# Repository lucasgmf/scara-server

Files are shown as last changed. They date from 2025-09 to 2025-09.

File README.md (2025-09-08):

# 4-DOF Educational SCARA Manipulator
An affordable, open-source robotic manipulator designed for educational environments, featuring four degrees of freedom and an integrated gripper system. Master's thesis in Electrical and Computer Engineering at the [Faculty of Engineering, University of Porto](https://www.up.pt/feup/en/).

## Dependencies
This project requires the following dependencies:

- [Python](https://www.python.org/)
- [ESP-IDF (Espressif IoT Development Framework)](https://docs.espressif.com/projects/esp-idf/en/stable/esp32/get-started/index.html)

If you are using the provided [Nix flake](./flake.nix), most of the dependencies are already handled.  
Make sure to install the ESP-IDF toolchain and source it before building:

```bash
. ~/esp-idf/export.sh
```

## Build & Flash (Makefile)
This project includes a `Makefile` that simplifies the workflow with the ESP-IDF toolchain.  
Instead of remembering multiple commands, you can just run `make` and it will take care of everything.

### Targets
- **`build`**  
  - Converts the web page `components/network/page.html` into a C header file (`page_html.h`) using `xxd`.  
    This allows embedding HTML directly into the firmware.  
  - Runs `idf.py build` to compile the project with ESP-IDF.

- **`flash`**  
  - Uploads the compiled firmware to the ESP32 via the specified serial port:  
    ```bash
    idf.py -p /dev/ttyUSB0 flash
    ```
  - If your board shows up differently, you can change the port (e.g. `/dev/ttyACM0`).

- **`monitor`**  
  - Starts the ESP-IDF serial monitor:  
    ```bash
    idf.py monitor
    ```
  - Useful for reading logs and debugging output from the ESP32.

- **`all`**  
  - Runs `build → flash → monitor` in sequence.  
  - This is also the **default target**, meaning just running:
    ```bash
    make
    ```
    will compile, flash, and open the serial monitor in one step.

### Example workflow
```bash
# Build the firmware only
make build

# Flash the firmware to ESP32
make flash

# Open the ESP-IDF monitor
make monitor

# Do everything: build, flash, and monitor
make
```

## Internet Connectivity
To enable Wi-Fi connectivity on the ESP32, you need to provide your own network credentials.

1. Open the template file located at:
```bash
components/network/credentials_TEMPLATE.h
```

2. Edit the file and replace the placeholders with your Wi-Fi details:
```c
   #ifndef CREDENTIALS_H
   #define CREDENTIALS_H

   #define WIFI_USERNAME "upxxxxxxxxx@up.pt"
   #define WIFI_PASSWORD "password"

   #endif
```
Where:
   - WIFI_USERNAME → your Wi-Fi SSID (e.g., the network name or enterprise username)
   - WIFI_PASSWORD → your Wi-Fi password

3. Save the file and rename it from:
   credentials_TEMPLATE.h
   to:
   credentials.h

Do not commit your personal credentials to GitHub ;).

# Kinematics Study
This repository also contains a directory for studying the kinematics of the SCARA robot.

You can find it here:
```bash
kinematics-study/kinematics.ipynb
```
Open the Jupyter notebook to explore the mathematical models and simulations of the robot's kinematics.

Tip: To run the notebook, make sure you have Python and Jupyter installed. Or run the notebook directly in [Google Colab](https://colab.google/).

# SCARA Robot Schematic
The electrical schematic of the SCARA robot is included in this repository.

Files included:
1. `schematic/scara_robot.json`  
   - This is the EasyEDA project file.  
   - You can open it directly in [EasyEDA](https://easyeda.com) to view, edit, or export the schematic.

2. `schematic/scara_robot.pdf`  
   - A static PDF version of the schematic for easy reference or printing.

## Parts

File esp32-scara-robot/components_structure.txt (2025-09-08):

components/
├── app/
│   ├── scara_controller.c 
│   └── scara_tasks.c
│
├── control/
│   └── pid.c 
│
├── devices/
│   ├── mag_encoder.c
│   ├── loadcell.c
│   └── motor_d.c
│
├── drivers/
│   └── i2c_bus.c          
│
├── hal/
│   ├── encoder.c   
│   ├── switch_h.c
│   ├── i2c_multiplexer.c
│   └── motor.c
│
└── network/
    ├── wifi_manager
    └── page.html

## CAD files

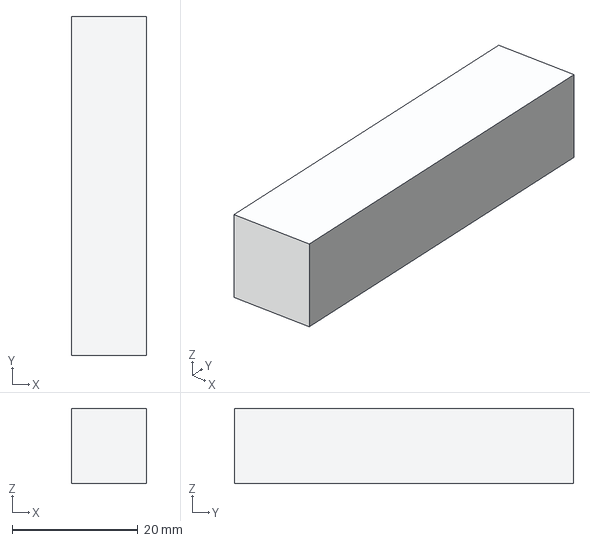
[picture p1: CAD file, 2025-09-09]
cad/step-files/Devices/Loadcell1.step
12.0 x 54.0 x 12.0 mm

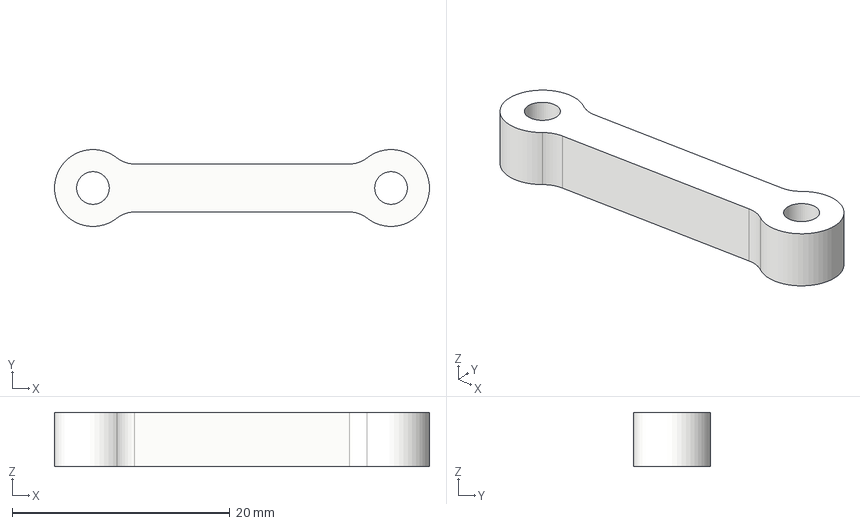
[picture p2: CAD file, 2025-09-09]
cad/step-files/FingerHolder.step
34.4 x 7.05 x 5.00 mm

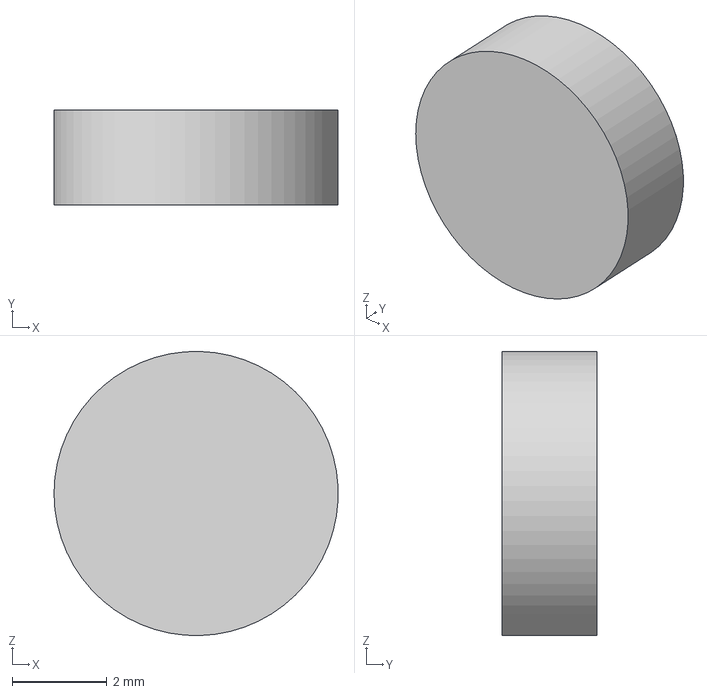
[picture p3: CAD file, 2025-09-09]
cad/step-files/Devices/magnet.step
6.00 x 2.00 x 6.00 mm

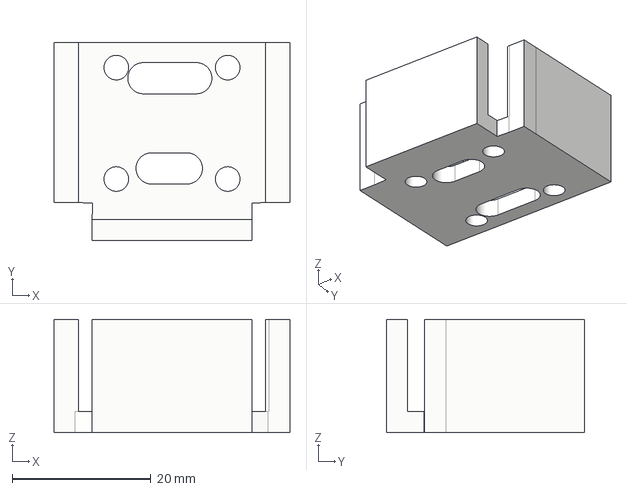
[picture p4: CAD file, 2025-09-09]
cad/step-files/EncoderHolderType1.step
34.0 x 28.5 x 16.3 mm

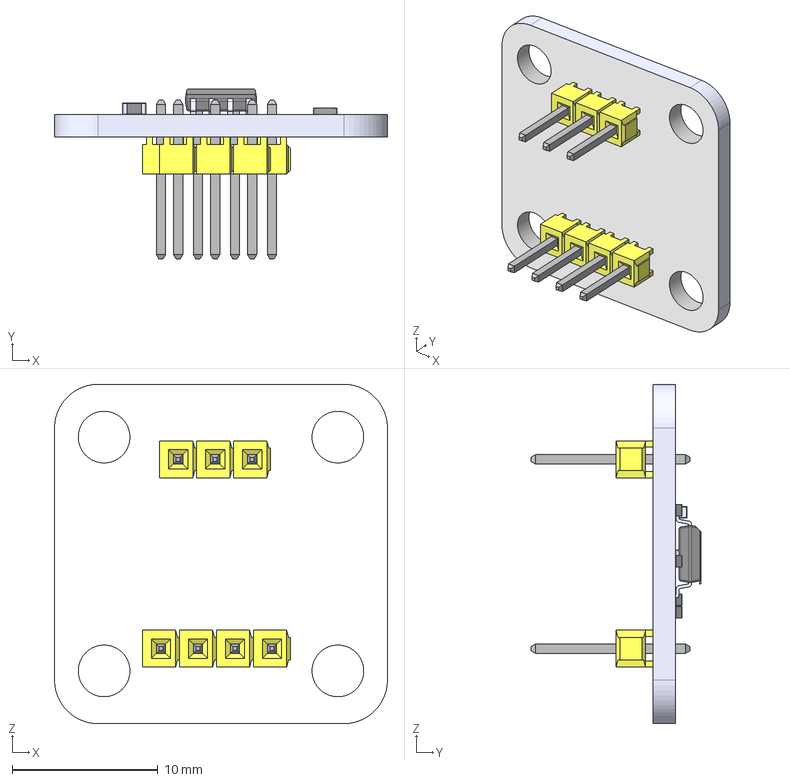
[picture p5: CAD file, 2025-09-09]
cad/step-files/Devices/AS5600.step
22.9 x 11.7 x 23.3 mm

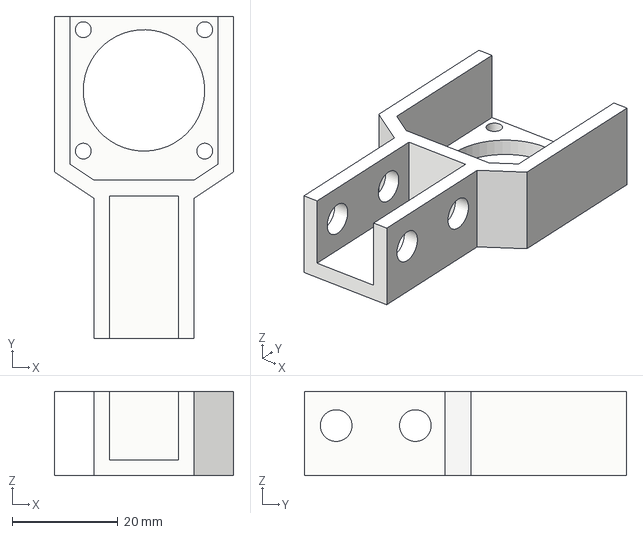
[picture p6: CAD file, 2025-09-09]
cad/step-files/LinkExtender.step
34.0 x 61.0 x 16.0 mm

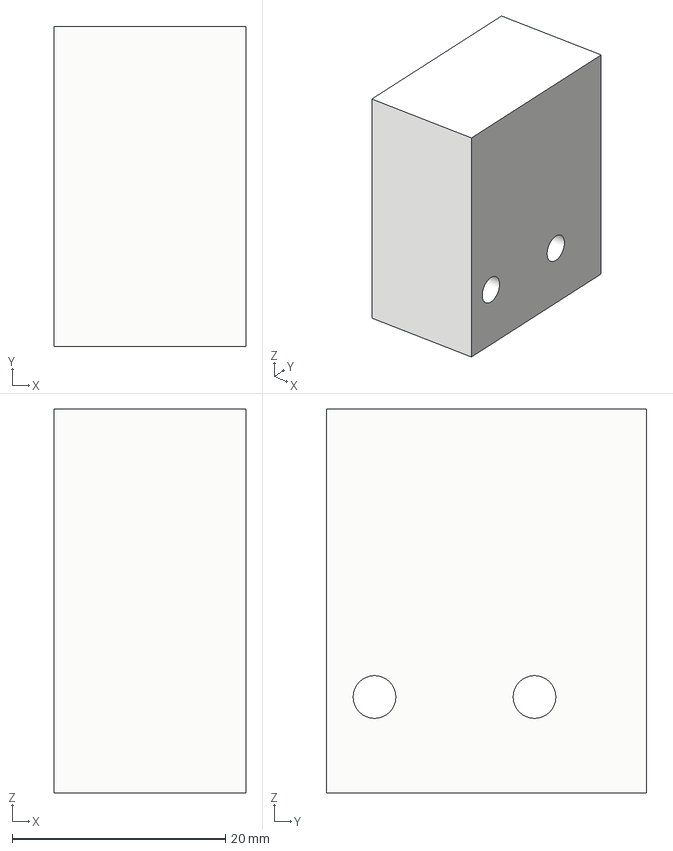
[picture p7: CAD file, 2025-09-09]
cad/step-files/Devices/LoadcellBase.step
18.0 x 30.0 x 36.0 mm

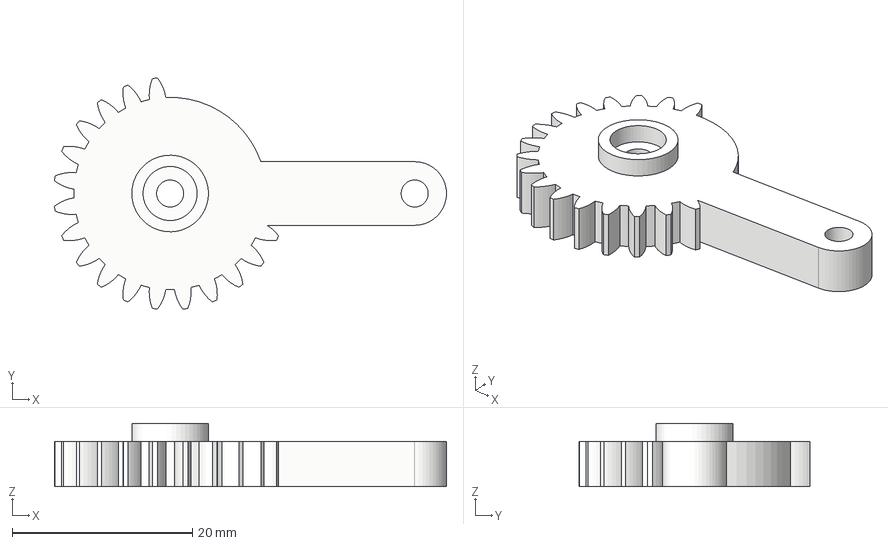
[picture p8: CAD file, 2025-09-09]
cad/step-files/GearArmType1.step
43.5 x 25.6 x 7.00 mm

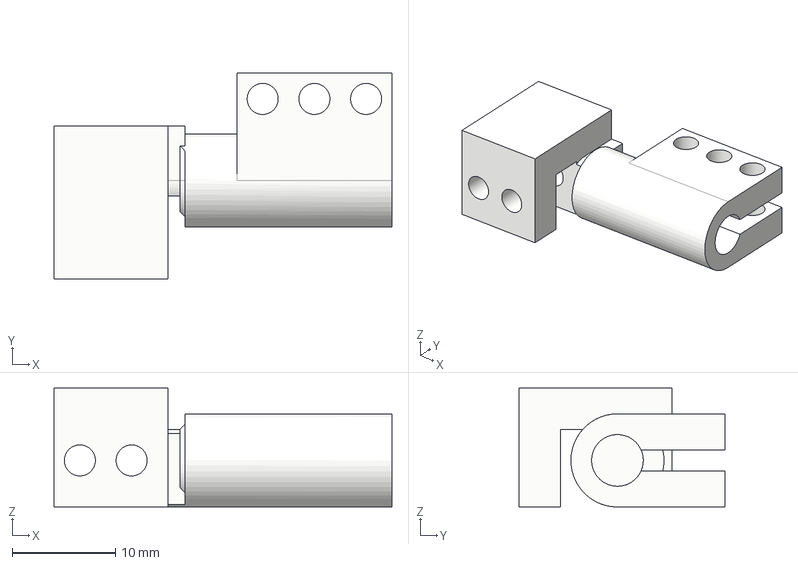
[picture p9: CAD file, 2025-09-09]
cad/step-files/NemaLinkGripper.step
32.7 x 19.9 x 11.5 mm

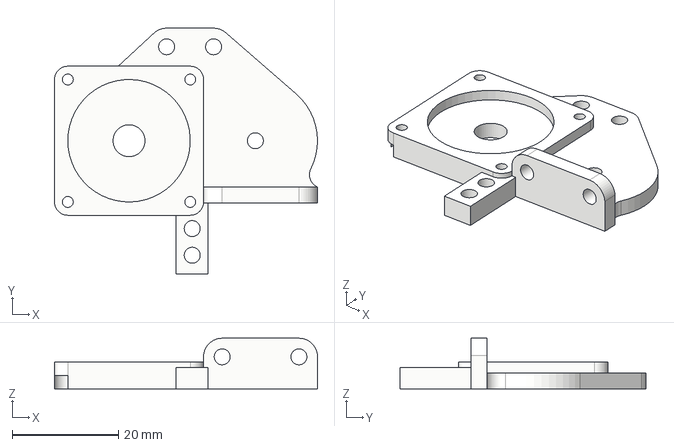
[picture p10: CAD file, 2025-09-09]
cad/step-files/ClawBody.step
49.4 x 46.1 x 9.50 mm

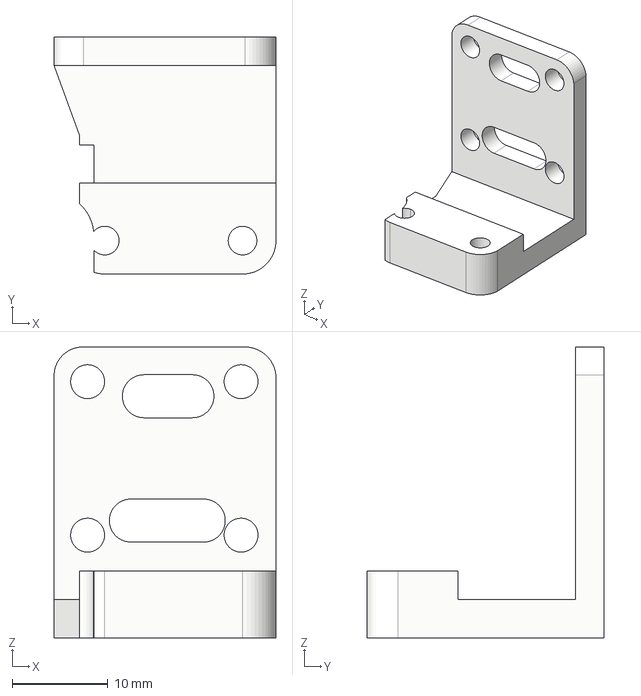
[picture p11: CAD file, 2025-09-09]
cad/step-files/EncoderHolderType2.step
23.2 x 24.8 x 30.4 mm

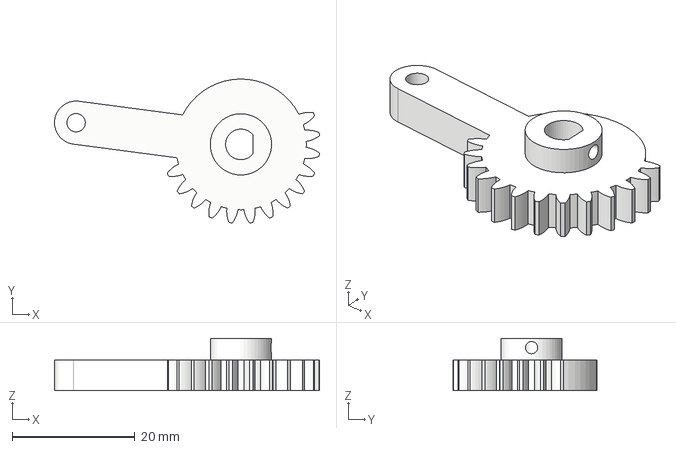
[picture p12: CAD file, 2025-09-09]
cad/step-files/GearArmType2.step
43.2 x 23.5 x 8.50 mm

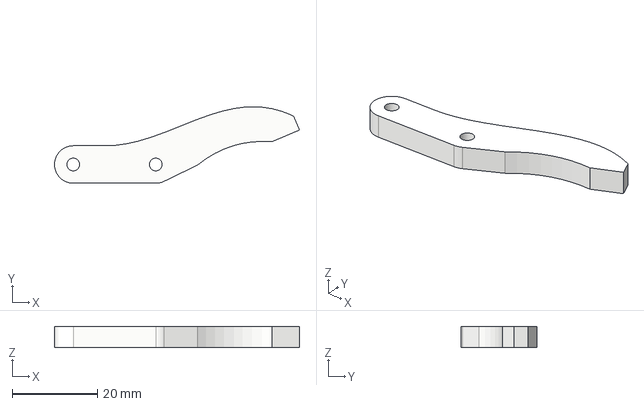
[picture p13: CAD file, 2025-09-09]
cad/step-files/Finger.step
57.6 x 18.0 x 5.00 mm

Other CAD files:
cad/fusion-files(.f3d)/ClawBody.f3d
cad/fusion-files(.f3d)/Devices/AS5600.f3d
cad/fusion-files(.f3d)/Devices/Loadcell1.f3d
cad/fusion-files(.f3d)/Devices/LoadcellBase.f3d
cad/fusion-files(.f3d)/Devices/NEMA11.f3d
cad/fusion-files(.f3d)/Devices/magnet.f3d
cad/fusion-files(.f3d)/EncoderHolderType1.f3d
cad/fusion-files(.f3d)/EncoderHolderType2.f3d
cad/fusion-files(.f3d)/Finger.f3d
cad/fusion-files(.f3d)/FingerHolder.f3d
cad/fusion-files(.f3d)/GearArmType1.f3d
cad/fusion-files(.f3d)/GearArmType2.f3d
cad/fusion-files(.f3d)/LinkExtender.f3d
cad/fusion-files(.f3d)/NemaLinkGripper.f3d
cad/fusion-files(.f3d)/assembledClaw.f3d

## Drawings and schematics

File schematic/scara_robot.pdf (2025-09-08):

# SD2 13 SC2 14 SD3 15 SC3 16 SD4 17 SC4 18 SD5 19

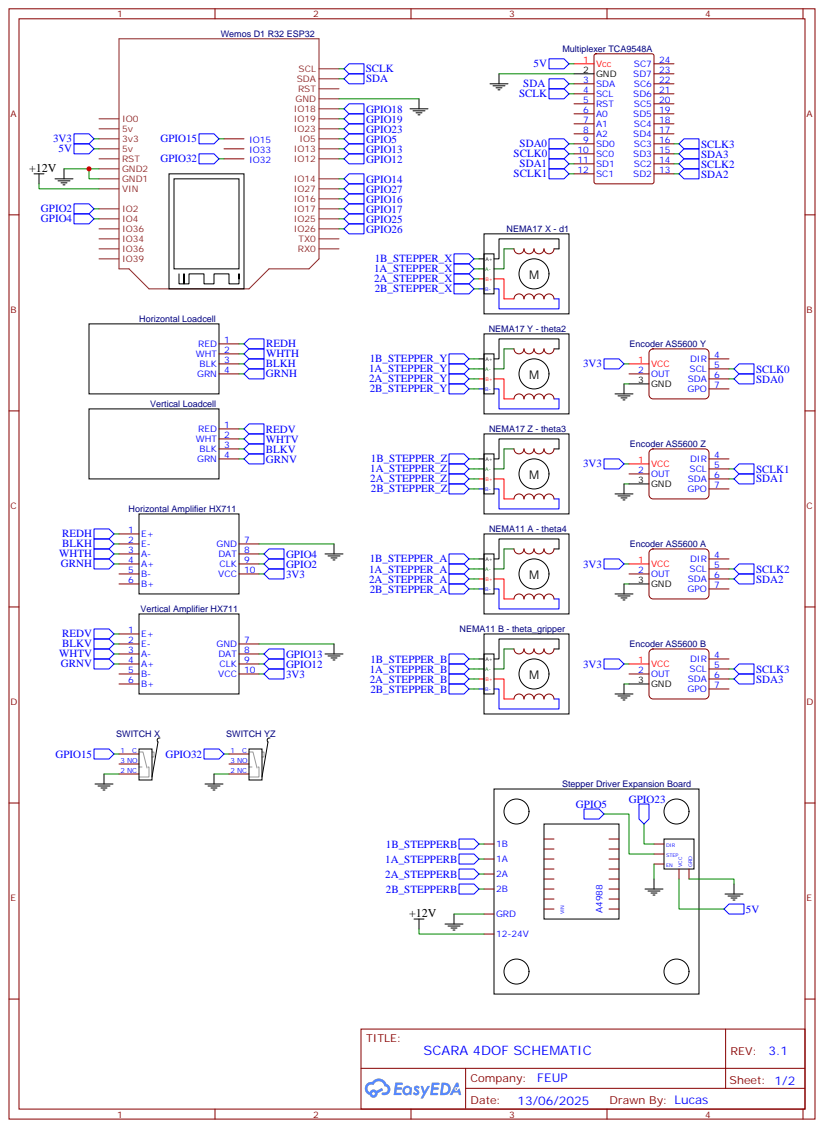
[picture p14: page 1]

Stepper Driver Expansion Board VIN

# CNC Shield V3

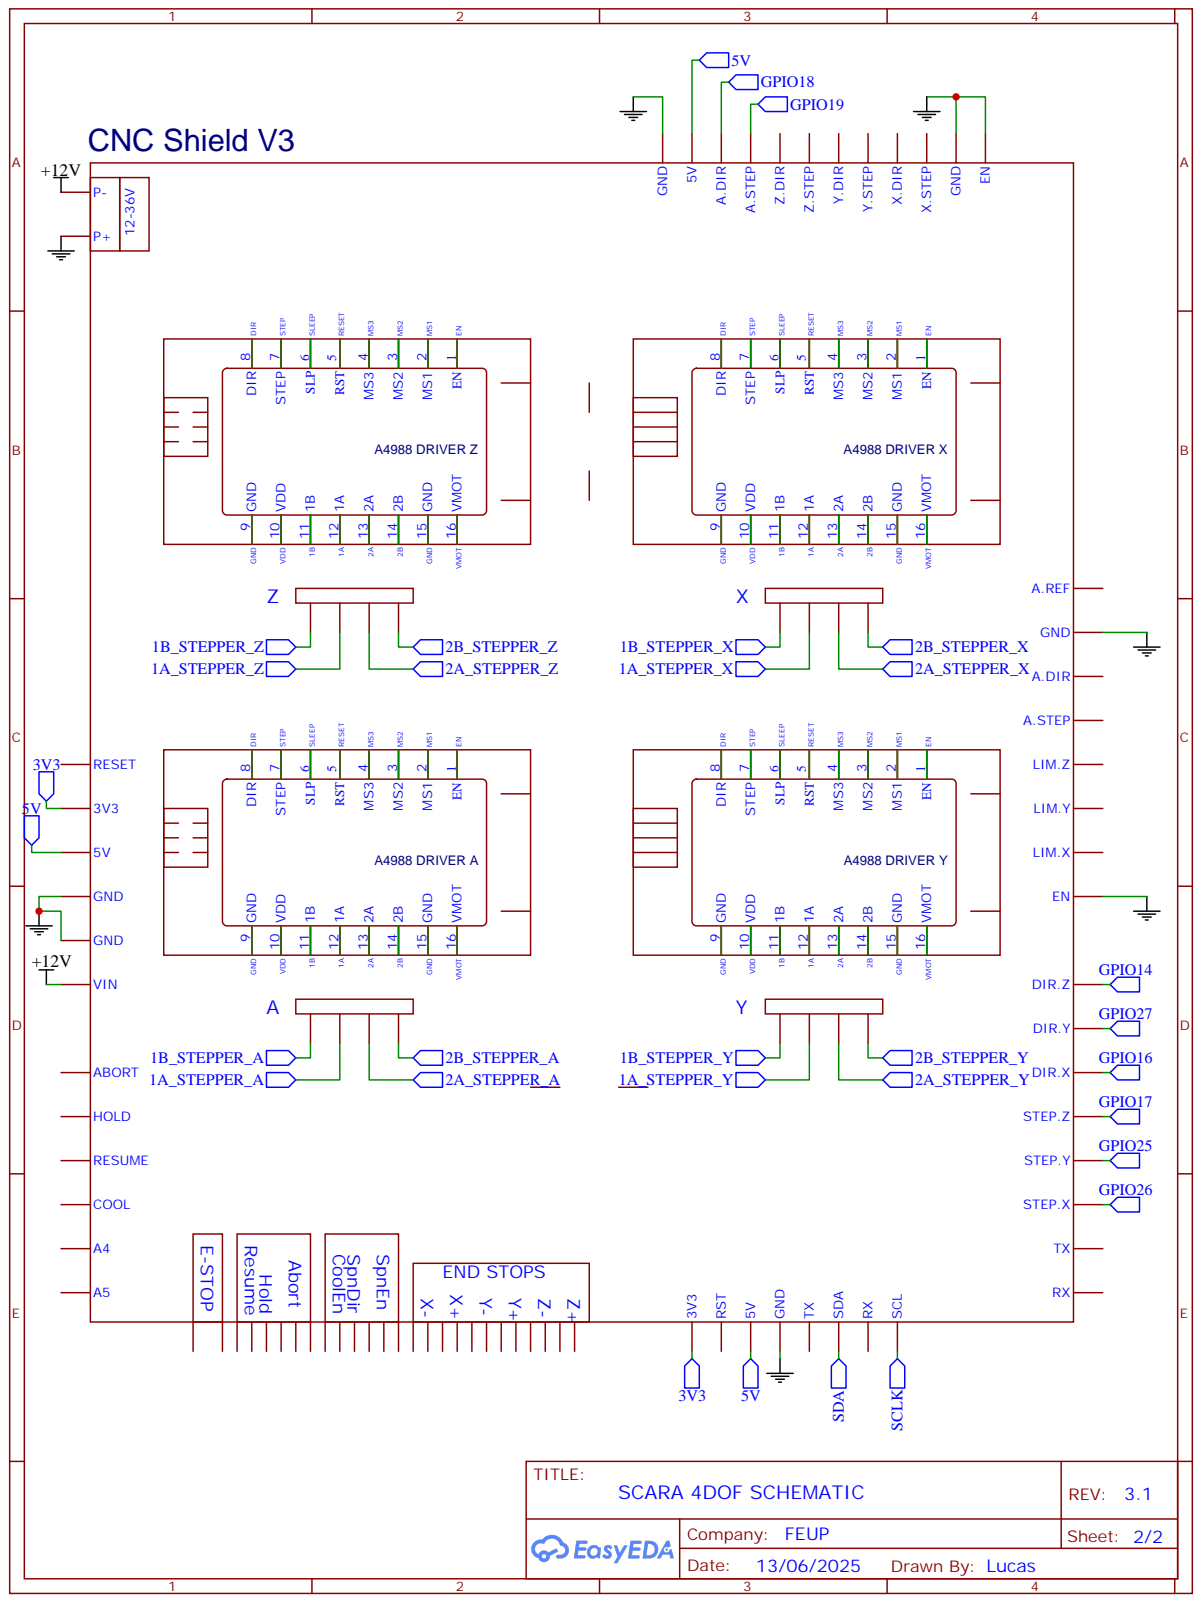
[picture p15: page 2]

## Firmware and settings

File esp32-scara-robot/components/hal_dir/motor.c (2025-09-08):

#include "motor.h"

static const char *TAG = "motor.c";

void motor_init_dir(motor_t *motor_n) {
  if (motor_n == NULL) {
    ESP_LOGI(TAG, "Pointer is null in motor_init_dir\n");
    return;
  }
  gpio_reset_pin(motor_n->gpio_dir);
  gpio_set_direction(motor_n->gpio_dir, GPIO_MODE_OUTPUT);
  ESP_LOGI(TAG, "Successfully initializated dir from motor %d", motor_n->id);

  return;
}

void motor_stop_pwm(motor_t *motor) {
  if (motor == NULL || motor->mcpwm_vars->timer == NULL) {
    return;
  }

  // Check if timer is already stopped/disabled to avoid errors
  esp_err_t err;

  // Try to stop the timer first - only if it's not already stopped
  err =
      mcpwm_timer_start_stop(motor->mcpwm_vars->timer, MCPWM_TIMER_STOP_EMPTY);
  if (err != ESP_OK && err != ESP_ERR_INVALID_STATE) {
    ESP_LOGW(TAG, "Failed to stop timer: %s", esp_err_to_name(err));
  }

  // Try to disable the timer - only if it's not already disabled
  err = mcpwm_timer_disable(motor->mcpwm_vars->timer);
  if (err != ESP_OK && err != ESP_ERR_INVALID_STATE) {
    ESP_LOGW(TAG, "Failed to disable timer: %s", esp_err_to_name(err));
  }

  // Force GPIO to LOW to eliminate noise
  gpio_set_level(motor->gpio_stp, 0);

  /* ESP_LOGI(TAG, "PWM cleanly stopped, GPIO set to LOW"); */
}

void motor_delete_pwm(motor_t *motor) {
  if (motor == NULL) {
    ESP_LOGW(TAG, "Pointer is null in motor_delete_pwm");
    return;
  }

  bool cleanup_gpio = false;

  // Stop timer first if it exists
  if (motor->mcpwm_vars->timer) {
    // Try to stop first, but silently ignore "already stopped" errors
    mcpwm_timer_start_stop(motor->mcpwm_vars->timer, MCPWM_TIMER_STOP_EMPTY);

    // Try to disable, but silently ignore "already disabled" errors
    mcpwm_timer_disable(motor->mcpwm_vars->timer);

    // Now delete the timer
    esp_err_t err = mcpwm_del_timer(motor->mcpwm_vars->timer);
    if (err != ESP_OK) {
      ESP_LOGW(TAG, "Error deleting timer: %s", esp_err_to_name(err));
    }
    motor->mcpwm_vars->timer = NULL;
  }

  if (motor->mcpwm_vars->generator) {
    esp_err_t err = mcpwm_del_generator(motor->mcpwm_vars->generator);
    if (err != ESP_OK) {
      ESP_LOGW(TAG, "Error deleting generator: %s", esp_err_to_name(err));
    }
    motor->mcpwm_vars->generator = NULL;
  }

  if (motor->mcpwm_vars->comparator) {
    esp_err_t err = mcpwm_del_comparator(motor->mcpwm_vars->comparator);
    if (err != ESP_OK) {
      ESP_LOGW(TAG, "Error deleting comparator: %s", esp_err_to_name(err));
    }
    motor->mcpwm_vars->comparator = NULL;
  }

  if (motor->mcpwm_vars->operator) {
    esp_err_t err = mcpwm_del_operator(motor->mcpwm_vars->operator);
    if (err != ESP_OK) {
      ESP_LOGW(TAG, "Error deleting operator: %s", esp_err_to_name(err));
    }
    motor->mcpwm_vars->operator= NULL;
    cleanup_gpio =
        true; // Only cleanup GPIO if operator was successfully deleted
  }

  if (cleanup_gpio) {
    gpio_reset_pin(motor->gpio_stp);
    gpio_set_direction(motor->gpio_stp, GPIO_MODE_OUTPUT);
    gpio_set_level(motor->gpio_stp, 0);
  }
}

void motor_create_pwm(motor_t *motor) {
  if (motor == NULL) {
    ESP_LOGE(TAG, "Parameter is null, aborting.");
    return;
  }

  motor_delete_pwm(motor);

  // For initialization, don't create PWM if frequency is 0 or too low
  if (motor->pwm_vars->current_freq_hz <= 0.0f) {
    /* ESP_LOGI(TAG, "PWM creation skipped for motor %d (freq = %.2f Hz)", */
    /*          motor->id, motor->pwm_vars->current_freq_hz); */
    return;
  }

  if (motor->pwm_vars->current_freq_hz < motor->pwm_vars->min_freq) {
    /* ESP_LOGW(TAG, "Skipping PWM creation: freq = %.2f is too low", */
    /*          motor->pwm_vars->current_freq_hz); */
    return;
  }

  // Clamp frequency to a safe range
  float freq = motor->pwm_vars->current_freq_hz;
  if (freq > motor->pwm_vars->max_freq)
    freq = motor->pwm_vars->max_freq;
  if (freq < motor->pwm_vars->min_freq)
    freq = motor->pwm_vars->min_freq;

  uint32_t period_ticks =
      (uint32_t)(motor->mcpwm_vars->pwm_resolution_hz / freq);
  if (period_ticks < motor->mcpwm_vars->mcpwm_min_period_ticks)
    period_ticks = motor->mcpwm_vars->mcpwm_min_period_ticks;
  if (period_ticks > motor->mcpwm_vars->mcpwm_max_period_ticks)
    period_ticks = motor->mcpwm_vars->mcpwm_max_period_ticks;

  uint32_t duty_ticks = period_ticks / 2;

  // Create timer
  mcpwm_timer_config_t timer_config = {
      .group_id = motor->mcpwm_vars->group_unit,
      .clk_src = MCPWM_TIMER_CLK_SRC_DEFAULT,
      .resolution_hz = motor->mcpwm_vars->pwm_resolution_hz,
      .period_ticks = period_ticks,
      .count_mode = MCPWM_TIMER_COUNT_MODE_UP,
  };

  esp_err_t err;
  err = mcpwm_new_timer(&timer_config, &motor->mcpwm_vars->timer);
  if (err != ESP_OK) {
    ESP_LOGE(TAG, "Failed to create MCPWM timer: %s", esp_err_to_name(err));
    return;
  }

  // Create operator and connect timer
  mcpwm_operator_config_t operator_config = {
      .group_id = motor->mcpwm_vars->group_unit,
  };

  err = mcpwm_new_operator(&operator_config, &motor->mcpwm_vars->operator);
  if (err != ESP_OK) {
    ESP_LOGE(TAG, "Failed to create MCPWM operator: %s", esp_err_to_name(err));
    return;
  }

  err = mcpwm_operator_connect_timer(motor->mcpwm_vars->operator,
                                     motor->mcpwm_vars->timer);
  if (err != ESP_OK) {
    ESP_LOGE(TAG, "Failed to connect operator to timer: %s",
             esp_err_to_name(err));
    return;
  }

  // Create comparator
  mcpwm_comparator_config_t comparator_config = {.flags.update_cmp_on_tez =
                                                     true};
  err = mcpwm_new_comparator(motor->mcpwm_vars->operator, & comparator_config,
                             &motor->mcpwm_vars->comparator);
  if (err != ESP_OK) {
    ESP_LOGE(TAG, "Failed to create comparator: %s", esp_err_to_name(err));
    return;
  }

  err = mcpwm_comparator_set_compare_value(motor->mcpwm_vars->comparator,
                                           duty_ticks);
  if (err != ESP_OK) {
    ESP_LOGE(TAG, "Failed to set compare value: %s", esp_err_to_name(err));
    return;
  }

  // Create generator
  mcpwm_generator_config_t generator_config = {.gen_gpio_num = motor->gpio_stp};
  err = mcpwm_new_generator(motor->mcpwm_vars->operator, & generator_config,
                            &motor->mcpwm_vars->generator);
  if (err != ESP_OK) {
    ESP_LOGE(TAG, "Failed to create generator: %s", esp_err_to_name(err));
    return;
  }

  err = mcpwm_generator_set_action_on_timer_event(
      motor->mcpwm_vars->generator,
      MCPWM_GEN_TIMER_EVENT_ACTION(MCPWM_TIMER_DIRECTION_UP,
                                   MCPWM_TIMER_EVENT_EMPTY,
                                   MCPWM_GEN_ACTION_HIGH));
  if (err != ESP_OK) {
    ESP_LOGE(TAG, "Failed to set generator high action: %s",
             esp_err_to_name(err));
    return;
  }
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

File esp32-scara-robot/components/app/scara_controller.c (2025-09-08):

#include "scara_controller.h"

static const char *TAG = "scara_controller";

//////////////////////////////////
////// network/wifi_manager //////
//////////////////////////////////

#include "cJSON.h"
#include "esp_http_server.h"

#ifndef MIN
#define MIN(a, b) ((a) < (b) ? (a) : (b))
#endif

wifi_config_t wifi_config_a = {
    .sta =
        {
            .ssid = "eduroam",
            .threshold.authmode = WIFI_AUTH_WPA2_ENTERPRISE,
            .sae_pwe_h2e = WPA3_SAE_PWE_BOTH,
            .failure_retry_cnt = 3,
        },
};

wifi_rec_data wifi_received_data = {
    .Kp = 1.2f,
    .Ki = 0.001f,
    .Kd = 0.1f,
    .target_position_1 = 2000,
    .target_position_2 = 2000,
};

user_input_data client_input_data = {
    .d1 = 1,
    .theta2 = 0,
    .theta3 = 0,
    .theta4 = 0,
    .x = 0,
    .y = 0,
    .z = 0,
    .w = 0,
    .dir_kinematics_on = 0,
    .inv_kinematics_on = 0,
    .pick_and_place_on = 0,
    .xip = 0,
    .yip = 0,
    .zip = 0,
    .wip = 0,
    .xfp = 0,
    .yfp = 0,
    .zfp = 0,
    .wfp = 0,
    .hp = 0,
    .cp = 0,
    .elbow_up = 0,
};

system_output_data system_output_data_values = {
    .horizontal_load = 0.0f,
    .vertical_load = 0.0f,
    .encoder0 = 0.0f,
    .encoder1 = 0.0f,
    .encoder2 = 0.0f,
    .encoder3 = 0.0f,
    .switch0 = 0,
    .switch1 = 0,
    .x = 0.0f,
    .y = 0.0f,
    .z = 0.0f,
    .w = 0.0f,
    .d1 = 0.0f,
    .theta2 = 0.0f,
    .theta3 = 0.0f,
    .theta4 = 0.0f,
    .theta5 = 0.0f,
};

system_output_data system_new_output_data_values = {
    .horizontal_load = 0.0f,
    .vertical_load = 0.0f,
    .encoder0 = 0.0f,
    .encoder1 = 0.0f,
    .encoder2 = 0.0f,
    .encoder3 = 0.0f,
    .switch0 = 0,
    .switch1 = 0,
    .x = 0.0f,
    .y = 0.0f,
    .z = 0.0f,
    .w = 0.0f,
    .d1 = 0.0f,
    .theta2 = 0.0f,
    .theta3 = 0.0f,
    .theta4 = 0.0f,
    .theta5 = 0.0f,
};

network_configuration esp_net_conf = {
    .wifi_config = &wifi_config_a,
    .port = PORT,
    .retry_num = 0,
    .rx_buffer_size = RX_BUFFER_SIZE,
    .addr_str_size = ADDR_STR_SIZE,
    .rec_data = &wifi_received_data,
    .s_wifi_event_group = (EventGroupHandle_t)&wifi_received_data,
    .user_input_data = &client_input_data,
    .system_output_data = &system_output_data_values,
};

// Global variables
static int g_client_sock = -1;
static SemaphoreHandle_t g_client_sock_mutex = NULL;
static SemaphoreHandle_t g_system_output_mutex = NULL;
static bool g_client_connected = false;
static SemaphoreHandle_t g_connection_mutex = NULL;

// Helper function to safely set client socket and connection status
void set_client_socket(int sock) {
  if (xSemaphoreTake(g_client_sock_mutex, pdMS_TO_TICKS(1000)) == pdTRUE) {
    g_client_sock = sock;
    xSemaphoreGive(g_client_sock_mutex);
  }

  if (xSemaphoreTake(g_connection_mutex, pdMS_TO_TICKS(1000)) == pdTRUE) {
    g_client_connected = (sock >= 0);
    xSemaphoreGive(g_connection_mutex);
  }
}

// Helper function to safely get client socket
int get_client_socket() {
  int sock = -1;
  if (xSemaphoreTake(g_client_sock_mutex, pdMS_TO_TICKS(1000)) == pdTRUE) {
    sock = g_client_sock;
    xSemaphoreGive(g_client_sock_mutex);
  }
  return sock;
}

bool is_client_connected() {
  bool connected = false;
  if (xSemaphoreTake(g_connection_mutex, pdMS_TO_TICKS(100)) == pdTRUE) {
    connected = g_client_connected;
    xSemaphoreGive(g_connection_mutex);
  }
  return connected;
}

bool handle_error(bool condition, const char *message, int sock_to_close) {
  if (condition) {
    ESP_LOGE(TAG, "%s: errno %d", message, errno);
    if (sock_to_close >= 0) {
      close(sock_to_close);
    }
    vTaskDelete(NULL);
    return true;
  }
  return false;
}
#include "cJSON.h"
#include "esp_http_server.h"
#include "esp_log.h"

static SemaphoreHandle_t g_user_input_mutex = NULL;

#include "page_html.h"

// HTTP GET handler for the main page
static esp_err_t root_get_handler(httpd_req_t *req) {
  httpd_resp_set_type(req, "text/html");
  httpd_resp_send(req, (const char *)components_network_page_html,
                  components_network_page_html_len);
  return ESP_OK;
}

// HTTP POST handler for control data
static esp_err_t control_post_handler(httpd_req_t *req) {
  char buf[512];
  int ret, remaining = req->content_len;

  if (remaining >= sizeof(buf)) {
    httpd_resp_send_err(req, HTTPD_400_BAD_REQUEST, "Content too large");
    return ESP_FAIL;
  }

  ret = httpd_req_recv(req, buf, MIN(remaining, sizeof(buf)));
  if (ret <= 0) {
    if (ret == HTTPD_SOCK_ERR_TIMEOUT) {
      httpd_resp_send_err(req, HTTPD_408_REQ_TIMEOUT, "Request timeout");
    }
    return ESP_FAIL;
  }

  buf[ret] = '\0';

  // Parse JSON data
  cJSON *json = cJSON_Parse(buf);
  if (json == NULL) {
    httpd_resp_send_err(req, HTTPD_400_BAD_REQUEST, "Invalid JSON");
    return ESP_FAIL;
  }

  // Create mutex if not exists
  if (g_user_input_mutex == NULL) {
    g_user_input_mutex = xSemaphoreCreateMutex();
  }

  // Update user input data with mutex protection
  if (xSemaphoreTake(g_user_input_mutex, pdMS_TO_TICKS(1000)) == pdTRUE) {
    cJSON *item;
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

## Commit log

2025-04-02 Structure update to esp32
2025-04-02 Testing build with blink-led
2025-04-03 removing blink-led to test wifi-connection
2025-04-03 Testing connection with esp32
2025-04-03 updated pc client to send random numbers to esp32 server
2025-04-03 now esp32 acts like a server instead a client
2025-04-20 working led version
2025-04-21 implementation of driver calibration
2025-04-22 initial initialization of motors
2025-04-24 Updating test functions to receive *motor arg
2025-04-24 removed led tests and updated code to use motor_t*
2025-04-24 using motor_t*
2025-04-24 Testing simple print tasks for future motor control
2025-04-24 implementation of motor_initialization() and beginning of motor_update()
2025-04-24 adding motor initialization to the main
2025-04-24 updated header with motor_update and motor_initialization
2025-04-29 implementation of the i2c drivers
2025-04-29 successfully reading the angle sensor
2025-04-29 trying to calibrate magnetic encoder + added switch logic
2025-04-30 created motor_task and motor_task_start
2025-04-30 using motor_move and motor_z
2025-04-30 cleanup of motor_task files
2025-04-30 refactoring motor.c and tasks
2025-05-05 renaming as5600 functions from sensor to mag_encoder
2025-05-05 added switch logic
2025-05-05 updated encoder update and calibration logic to a task
2025-05-05 removing old motor task code
2025-05-12 mag_encoder struct now includes needed pointers to i2c comm
2025-05-12 simple test using mcpwm to control motor_x
2025-05-12 function to update the pwm parameters added
2025-05-12 now including functions from motor_d
2025-05-12 testing motors x, y and z
2025-05-12 test tasks for testing motors x, y and z
2025-05-12 updated motor_t strct to include mcpwm parameters
2025-05-12 trying to fix reading bug
    [scara_controller.c, scara_tasks.c]
2025-05-13 removing broken i2c configuration
    [scara_controller.c]
2025-05-15 updating pwm as a task
2025-05-15 added missing motor_init_dir
2025-05-15 testing 2 motors with new lib
2025-05-15 fixed division by 0 and added safety if's
    [motor.c]
2025-05-15 adding and testing i2c logic
2025-05-19 making reading encoder as a task
2025-05-19 struct change to isolate configurations from the encoder to its i2c configs
2025-05-19 added edge case
2025-05-19 updating struct of motor_d
2025-05-19 fix print typo
2025-05-21 adding log from task_update_motor_pwm() and uncommenting encoder task call
2025-05-22 adding i2c scanner
2025-05-22 successful implementation of i2c communication
2025-05-22 tca_select_channel now needs a i2c_master_dev_handle_t
2025-05-22 adding i2c_multiplexer logic
2025-05-22 include i2c_multiplexer lib
2025-05-22 creating encoder task logic inside scara_tasks
2025-05-22 updating i2c structs
2025-05-22 encoder initialization and reading updated to new structs
2025-05-23 starting refactoring of motor logic
2025-05-24 major motor code changes
2025-05-26 adding encoder friendly stats
2025-05-26 updating switch logic
2025-05-26 starting calibration logic
2025-05-27 removed calibration logic
2025-05-27 motor cannot be calibrated, but encoders do :)
2025-05-27 updating calibration logic
2025-05-27 switches are now initialized before encoders
2025-05-29 fixing mutex logic when reading multiple encoders
    [encoder.c, i2c_multiplexer.c, scara_controller.c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]
2025-05-29 adding encoder_2
2025-05-30 adding 3rd encoder
2025-05-30 fixing pointer not pointing to mutex
    [scara_controller.c, scara_tasks.c]
2025-05-30 reading multiple encoders!
2025-06-02 testing only encoder0
2025-06-02 inverting direction logic at moor_control_task
    [scara_tasks.c]
2025-06-02 switches working!
2025-06-02 removing switch test prints
2025-06-04 encoders working!
2025-06-04 updating switches gpio port
2025-06-04 adding angle_degrees to encoder struct
2025-06-04 broken motor device
2025-06-04 fixing setting frequencies above 0 Hz
    [motor.c, scara_controller.c]
2025-06-04 broken acceleration at 0 hz
    [motor.c, scara_controller.c, scara_tasks.c]
2025-06-04 fixed acceleration at 0 Hz
    [motor.c]
2025-06-04 testing motors xyz
2025-06-09 adding motorb
2025-06-09 broken acceleration but better a
    [motor.c]
2025-06-10 Adding motorA
2025-06-10 updating max_freq of motor_x
2025-06-11 updating motor_x freqs
2025-06-18 testing motor_task
2025-06-18 fixed gpio dir and stp for motor A
    [scara_controller.h]
2025-06-18 starting calibration routines + setting offsets + pid changes
2025-06-18 removing encoder_0 offset
2025-06-20 initial implementation of load sensor
2025-06-24 reading from all sensors
2025-06-24 fixed accidental removal of encoder0_cfg.scl_speed_hz
    [scara_controller.c]
2025-06-25 testing motor_b
2025-06-26 decreasing the vTaskDelay of switch_task from 25 to 10 ms
2025-06-26 working x, y and z motors calibration
2025-07-04 trying to calibrate load cells
2025-07-04 pwm changes + attemp to calibrate load cells
2025-07-04 turning off pid logs
2025-07-04 updating motors' directions + testing position after calibration
2025-07-07 adding pid control to motor_a
2025-07-10 updating struct to include current and target positions to zz control
2025-07-11 reverting calibration on y and z
    [scara_controller.c]
2025-07-12 testing bidirectional comm in esp32
2025-07-17 upload kinematics study file
2025-07-17 major updates to inverse_kinematics. direct kin is now fixed, added is_point_reachable()
    [scara_controller.c]
2025-07-21 removing motor logs
2025-07-21 trying new approach of client communication. esp32 now hosts the page
2025-07-22 added logs to confirm esp32 actually receives and updates the values in local memory from commun with client
2025-07-23 adding new parameter claw % to control claw opening value
2025-07-23 adding claw % to all modes
2025-07-23 renaming reset to home button to reset values
2025-07-24 updating ratio for motor_a + fixing its inv kinematics
    [scara_controller.c]
2025-07-29 updating speed of motor_x + new function to print thesis results
2025-08-06 adding new print debug thread + debug d1 output value
2025-09-08 Update README with kinematics study information
2025-09-08 Add SCARA robot schematic section to README
2025-09-09 adding cad files
    [AS5600.f3d, AS5600.step, ClawBody.f3d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]
